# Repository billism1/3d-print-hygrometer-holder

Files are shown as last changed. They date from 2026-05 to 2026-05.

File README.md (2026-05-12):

# Round Hygrometer Holder

Minimalistic U-shaped holder for the standard round mini hygrometer commonly sold on Amazon and similar sites. Designed with one priority above all else: **print fast, use little filament**. There are clever holders out there that use container geometry to self-secure — impressive engineering, but they come with longer print times and more filament. With over 70 filament spools to monitor, I just want to save time where I can.

Instead, this holder attaches with heavy-duty double-sided tape, which works remarkably well in practice. Better yet, the same simple design fits both common storage setups: the popular **cereal-style containers** and the **20-quart Sterilite containers** (the kind that fit 4 spools). If you use both — this holder covers both.

**Example compatible hygrometer:** [Amazon B098JFRNKM](https://www.amazon.com/dp/B098JFRNKM?ref_=ppx_hzsearch_conn_dt_b_fed_asin_title_1)

**Tip:** For best results, use "heavy duty" double-sided tape to mount the holder. Available on Amazon and similar sites.

## Target Device Dimensions

| Dimension | Value |
|---|---|
| Front lip outer diameter | 45 mm |
| Body outer diameter | 40 mm |
| Total depth | 15 mm |

## Renders

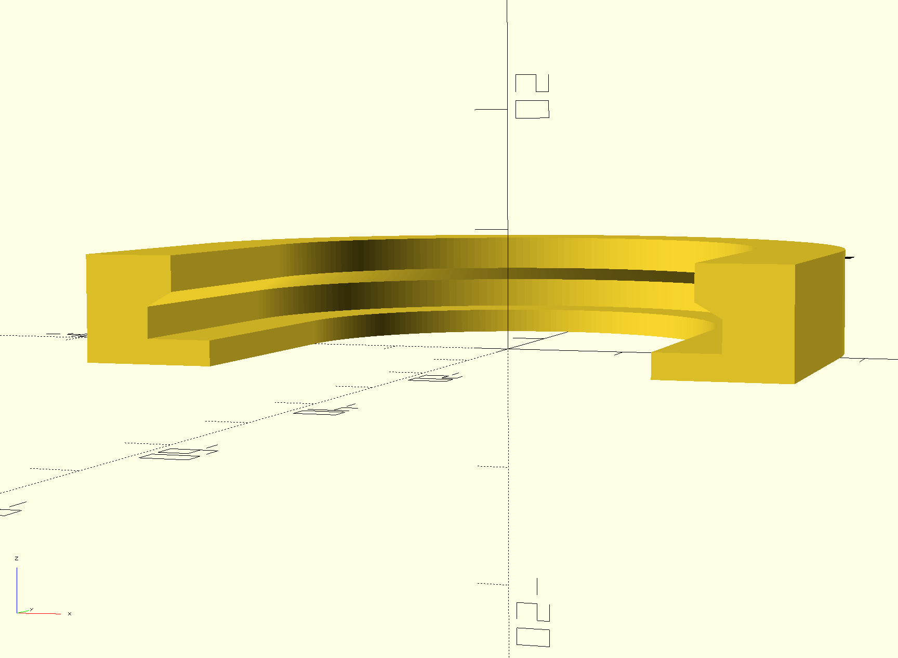
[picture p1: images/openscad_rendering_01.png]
Render 1

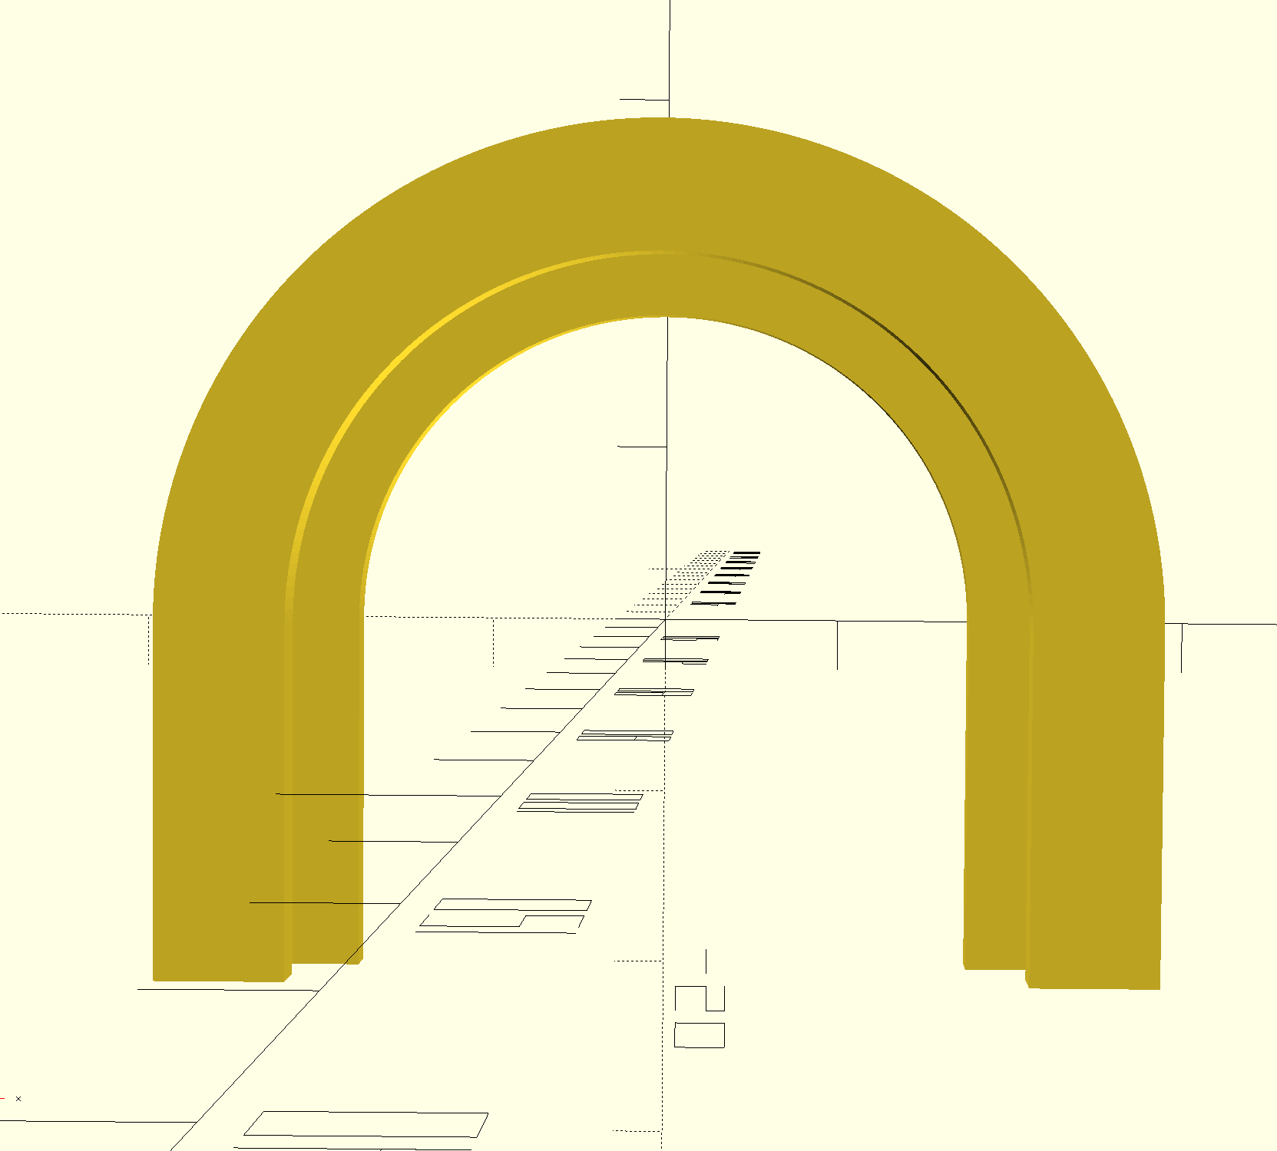
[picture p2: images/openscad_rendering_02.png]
Render 2


## Photos

### Cereal Box

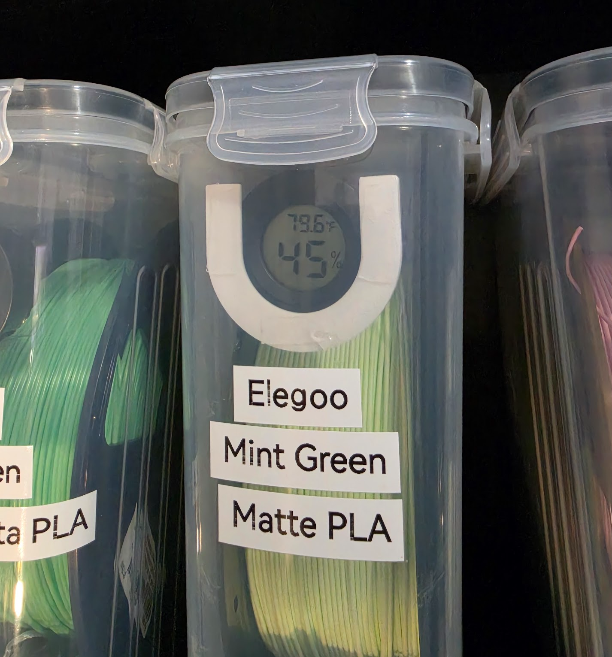
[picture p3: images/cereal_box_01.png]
Hygrometer holder on cereal box


### Sterilite Box

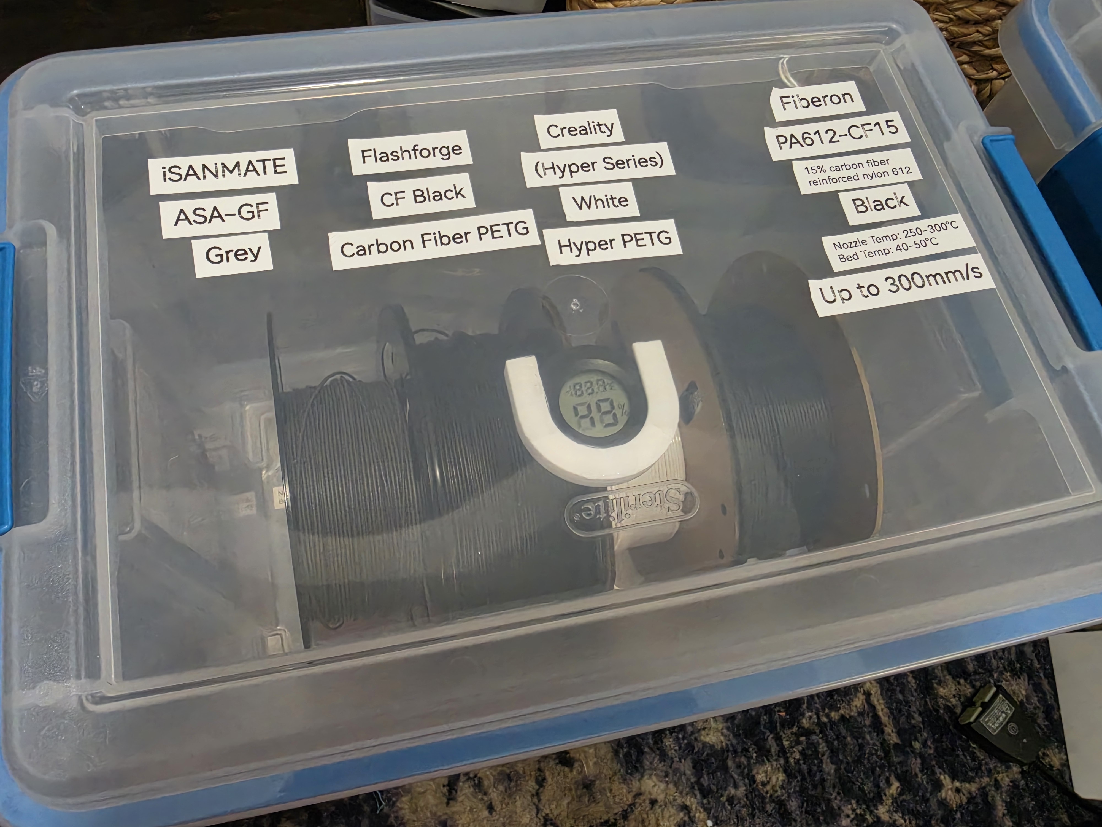
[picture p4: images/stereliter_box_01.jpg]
Sterilite box top — view from above


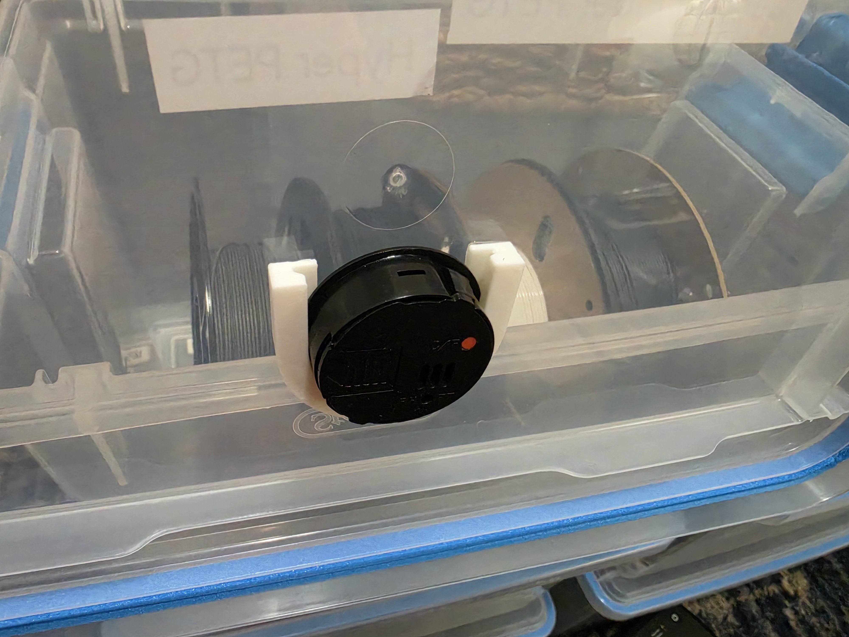
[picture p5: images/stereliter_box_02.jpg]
Sterilite box — hygrometer mounted on underside of lid


## Design

- U-shaped profile printed flat on the build plate (U lies on its side)
- 180° arc + two straight tangent arms form the U
- Inner stepped channel captures the hygrometer lip; body slides through freely
- Chamfered inner step (default 30°) minimizes overhang for support-free printing
- Fully parametric OpenSCAD source in `src/hygrometer-holder.scad`

### Key Parameters

| Parameter | Default | Description |
|---|---|---|
| `inner_bottom_r` | 17.5 mm | Front-stop radius (35 mm inner gap) |
| `lip_r` | 22.75 mm | Lip channel radius (45.5 mm gap) |
| `body_r` | 20.715 mm | Body channel radius (41.43 mm gap) |
| `outer_r` | 28 mm | Outer wall radius |
| `z_floor` | 2 mm | Front-stop ledge height |
| `z_lip_top` | 4.5 mm | Top of lip channel |
| `z_top` | 8.5 mm | Total holder height |
| `arm_length` | 20 mm | Straight arm extension length |
| `overhang_angle` | 30° | Chamfer angle on inner step |

## Print Settings

- **Supports:** None required (chamfered inner step)
- **Orientation:** Flat on bed as designed
- **Material:** PLA or PETG recommended
- **Infill:** 20–30%
- **Print time:** ~16 minutes (Bambu P1S, SUNLU PLA+ 2.0 filament profile, Bambu Lab standard quality)

## Repository Layout

- `src/` — OpenSCAD parametric source
- `publication/` — Platform-specific export folders (MakerWorld, Printables, etc.)

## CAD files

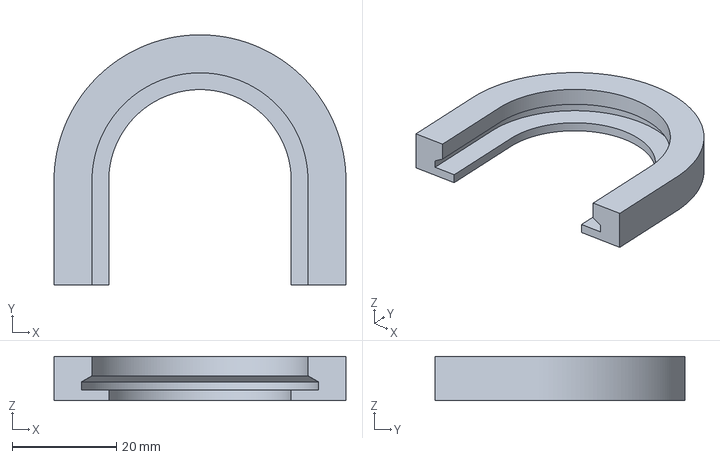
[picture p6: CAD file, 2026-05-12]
publication/hygrometer-holder.3mf
56.0 x 48.0 x 8.50 mm

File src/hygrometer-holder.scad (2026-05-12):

// Round hygrometer holder.
// Hygrometer: 45mm lip OD, 40mm body OD, 15mm thick.
// U lies flat on bed (rotate_extrude axis = Z = print Z).
// Shape: 180° arc + two tangent straight extensions = U.
// Slide device in from open end; lip captured in middle channel.

$fn = 200;

// Profile (radial X, Z height). Inner stepped wall, outer straight wall.
inner_bottom_r = 17.5;     // 35mm gap at bed (front-face stop)
lip_r          = 22.75;    // 45.5mm gap (lip channel, 45mm lip + clearance)
body_r         = 20.715;   // 41.43mm gap (body channel, 40mm body + clearance)
outer_r        = 28;       // ~5mm wall outside lip channel

z_floor   = 2;             // front-stop thickness
z_lip_top = 3.6;             // floor + 2.5mm lip channel
z_top     = 8.5;           // lip_top + 4mm body channel

arm_length = 20;            // straight tangent extension on each side

overhang_angle = 30;       // chamfer angle (deg from horizontal) at top inner step.
                           // 45° is steepest self-supporting overhang for FDM.
chamfer_dz = (lip_r - body_r) * tan(overhang_angle);

profile = [
    [inner_bottom_r, 0],
    [inner_bottom_r, z_floor],
    [lip_r,          z_floor],
    [lip_r,          z_lip_top],
    [body_r,         z_lip_top + chamfer_dz],   // chamfered top inner step
    [body_r,         z_top],
    [outer_r,        z_top],
    [outer_r,        0],
];

module arm() {
    // Profile placed in XZ plane (radial X from inner_bottom_r..outer_r),
    // extruded along -Y for arm_length.
    rotate([90, 0, 0])
        linear_extrude(height = arm_length)
            polygon(points = profile);
}

union() {
    // Top half arc (0° to 180° in XY plane).
    rotate_extrude(angle = 180)
        polygon(points = profile);

    // Right tangent arm (at angle 0°, extending -Y).
    arm();

    // Left tangent arm (mirrored across YZ plane).
    mirror([1, 0, 0]) arm();
}

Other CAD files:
publication/hygrometer-holder.stl

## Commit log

2026-05-12 add initial implementation of round hygrometer holder
    [hygrometer-holder.scad]
2026-05-12 refactor: update hygrometer holder design with arm extensions and improved comments
    [hygrometer-holder.scad]
2026-05-12 refactor: adjust chamfer for top inner step in hygrometer holder design
    [hygrometer-holder.scad]
2026-05-12 add hygrometer holder STL model file
    [hygrometer-holder.stl]
2026-05-12 fix: correct attachment description for hygrometer holder in README
2026-05-12 refactor: enhance README description and add print time; adjust lip height in SCAD model
    [hygrometer-holder.scad, hygrometer-holder.stl]
2026-05-12 Finish setting z_lip_top to 3 mm.
    [hygrometer-holder.scad, hygrometer-holder.stl]
2026-05-12 fix: update z_lip_top to 3.5 mm for improved lip channel fit
    [hygrometer-holder.scad, hygrometer-holder.stl]
2026-05-12 fix: correct z_lip_top value to 4.0 mm for accurate lip channel dimensions
    [hygrometer-holder.scad, hygrometer-holder.stl]
2026-05-12 fix: update z_lip_top value to 3.6 mm for accurate lip channel dimensions
    [hygrometer-holder.scad, hygrometer-holder.stl]
2026-05-12 Adding Bambu Lab 3mf file.
    [hygrometer-holder.3mf]
